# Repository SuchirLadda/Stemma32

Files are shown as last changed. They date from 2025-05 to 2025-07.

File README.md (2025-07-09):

# Stemma32
Custom STM32 dev board with UART, I²C, USB, and SWD interfaces. Designed in KiCad for embedded prototyping.

## Overview
A custom-designed STM32 development board featuring UART, I²C, and USB communication interfaces, intended for embedded systems prototyping and peripheral interfacing. This board is built around the STM32F103C8T6 microcontroller and includes key components such as an external crystal oscillator, onboard boot configuration switch, SWD programming header, and power regulation circuitry.

Pin layout and peripheral configuration were assisted by STM32CubeIDE, which was used to validate the pin mappings and peripheral assignments during design.

## Features
- STM32F103C8T6 MCU
- USB-to-Serial (UART) communication
- UART and I²C breakout for peripherals
- SWD programming/debug interface
- Onboard 3.3V AMS1117 voltage regulator
- External 8 MHz crystal oscillator
- Boot configuration slide switch  
- KiCad 8 project files included

## Repository Contents
- `/kicad/` – Schematic and PCB layout
- `/images/` – 3D model and board render

### Front View – 3D PCB Render
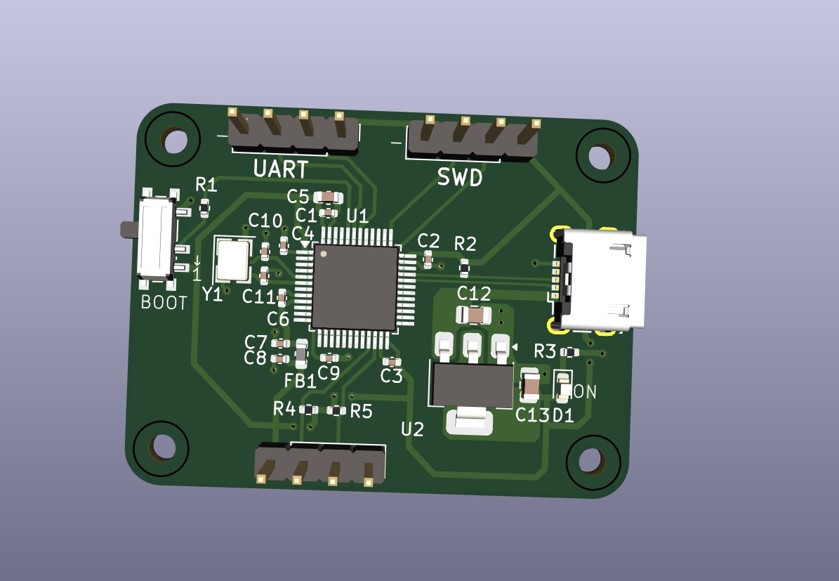
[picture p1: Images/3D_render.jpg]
STM32 Board Render


### Rear View – 3D PCB Render
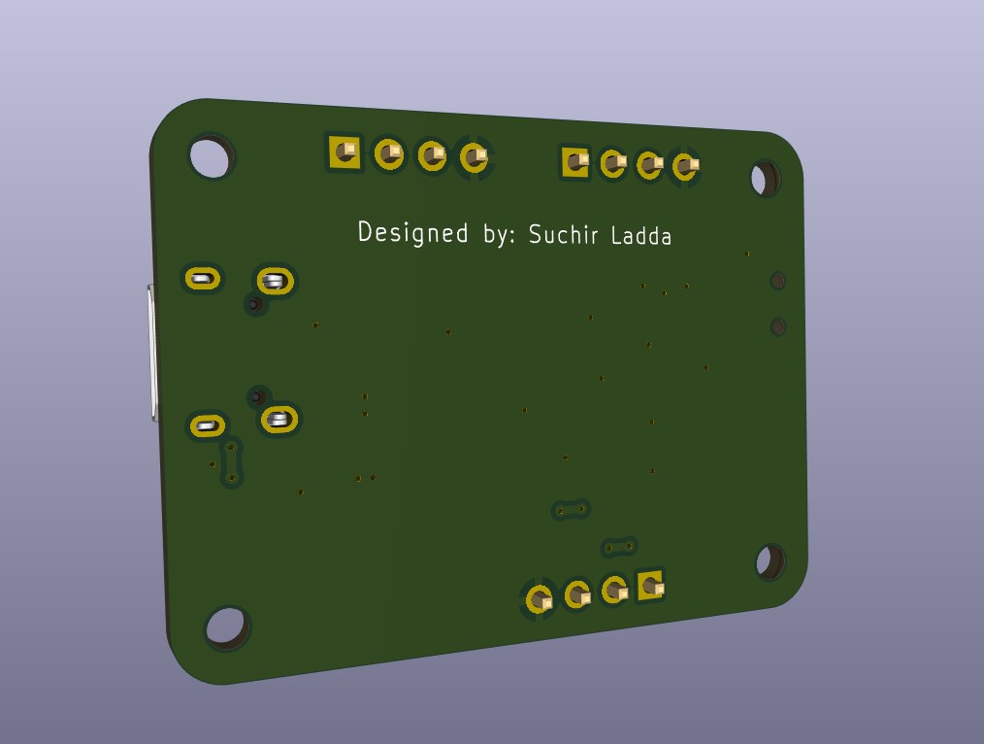
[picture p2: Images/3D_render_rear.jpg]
STM32 Board Render


## 🤝 Sponsorship

This board was manufactured and assembled with the generous support of **[PCBWay](https://www.pcbway.com/)**.

The production quality and turnaround time were excellent. From fabrication to component assembly, everything arrived perfectly aligned and functional.

PCBWay’s engineering team responds quickly and is very understanding when it comes to resolving issues in the assembly process. I highly recommend them for custom PCB projects.

## Physical Board Photos

### Assembled Board – Front
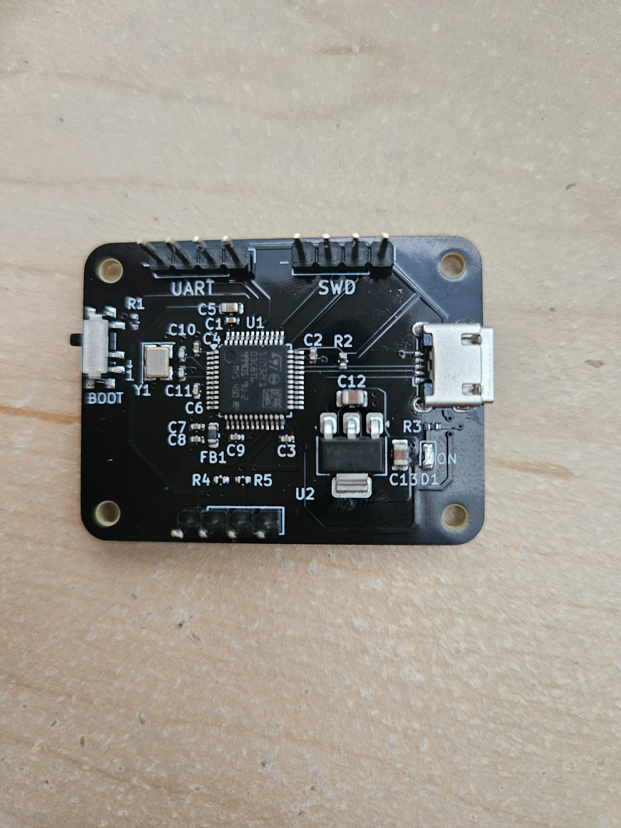
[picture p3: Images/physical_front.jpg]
STM32 Board Front


### Assembled Board – Rear
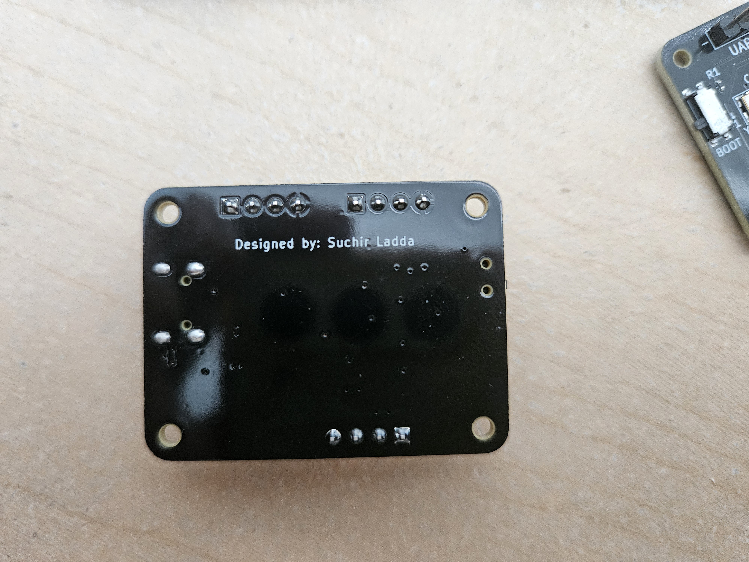
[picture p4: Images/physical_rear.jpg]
STM32 Board Rear


### Power Indicator Test
Power LED On

### All Units Assembled
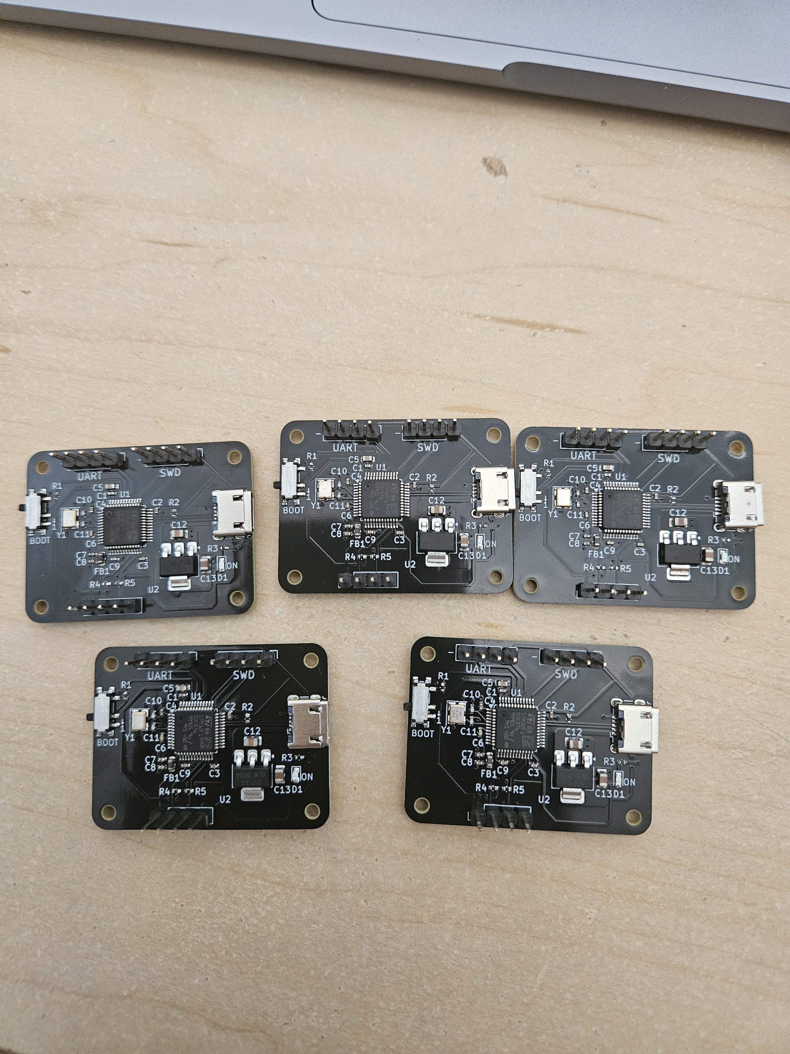
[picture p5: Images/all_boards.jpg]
Batch of Boards


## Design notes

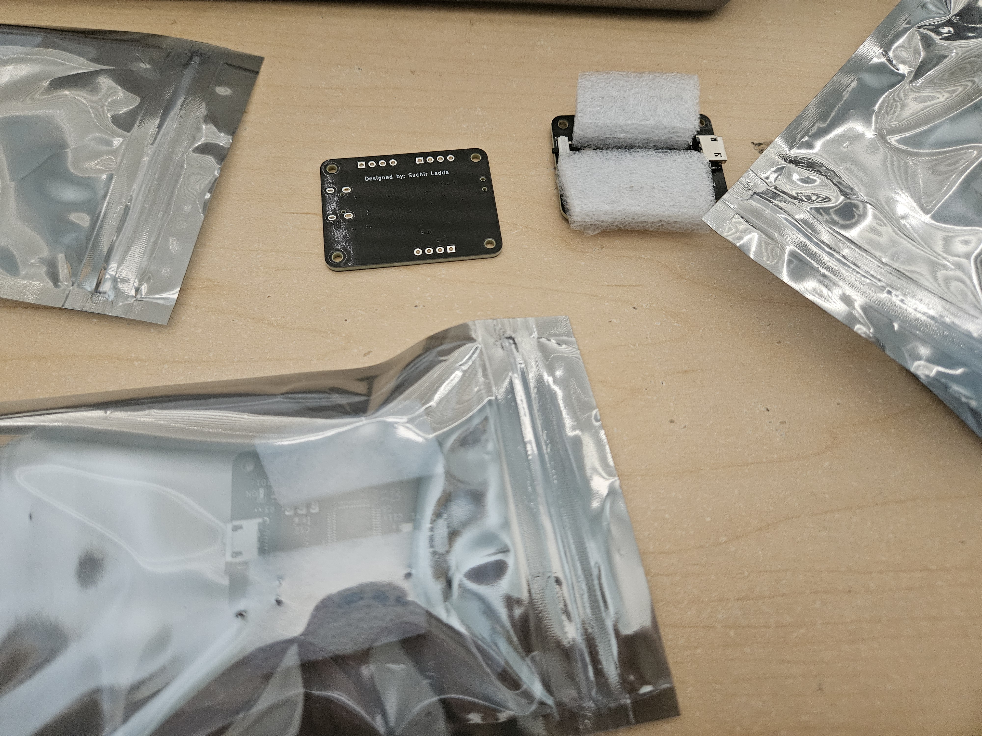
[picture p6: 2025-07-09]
Images/package.jpg

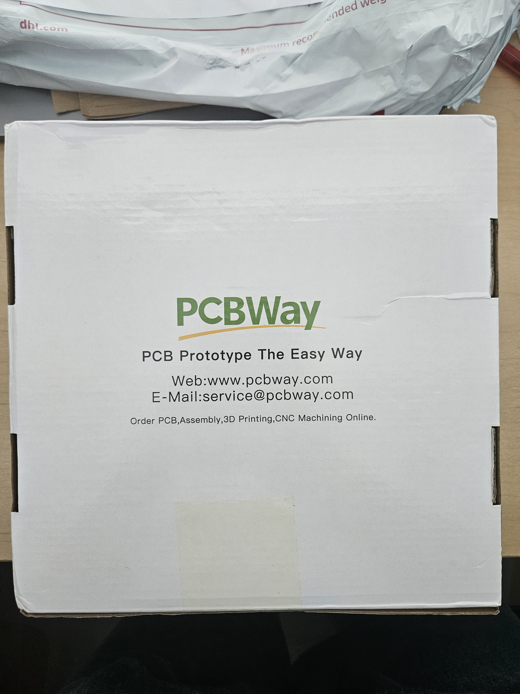
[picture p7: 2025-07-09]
Images/box.jpg

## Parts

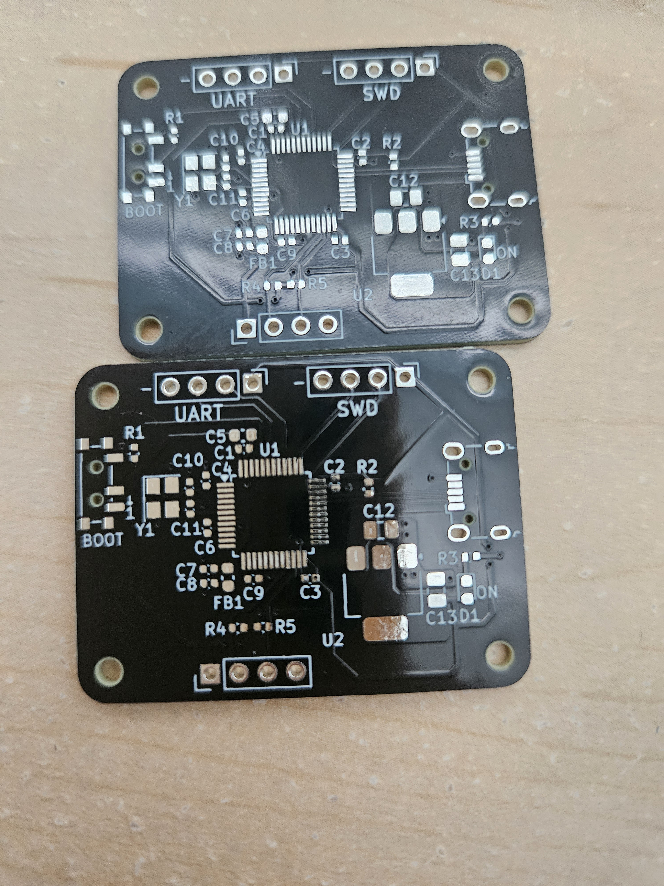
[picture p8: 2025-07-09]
Images/no_components.jpg

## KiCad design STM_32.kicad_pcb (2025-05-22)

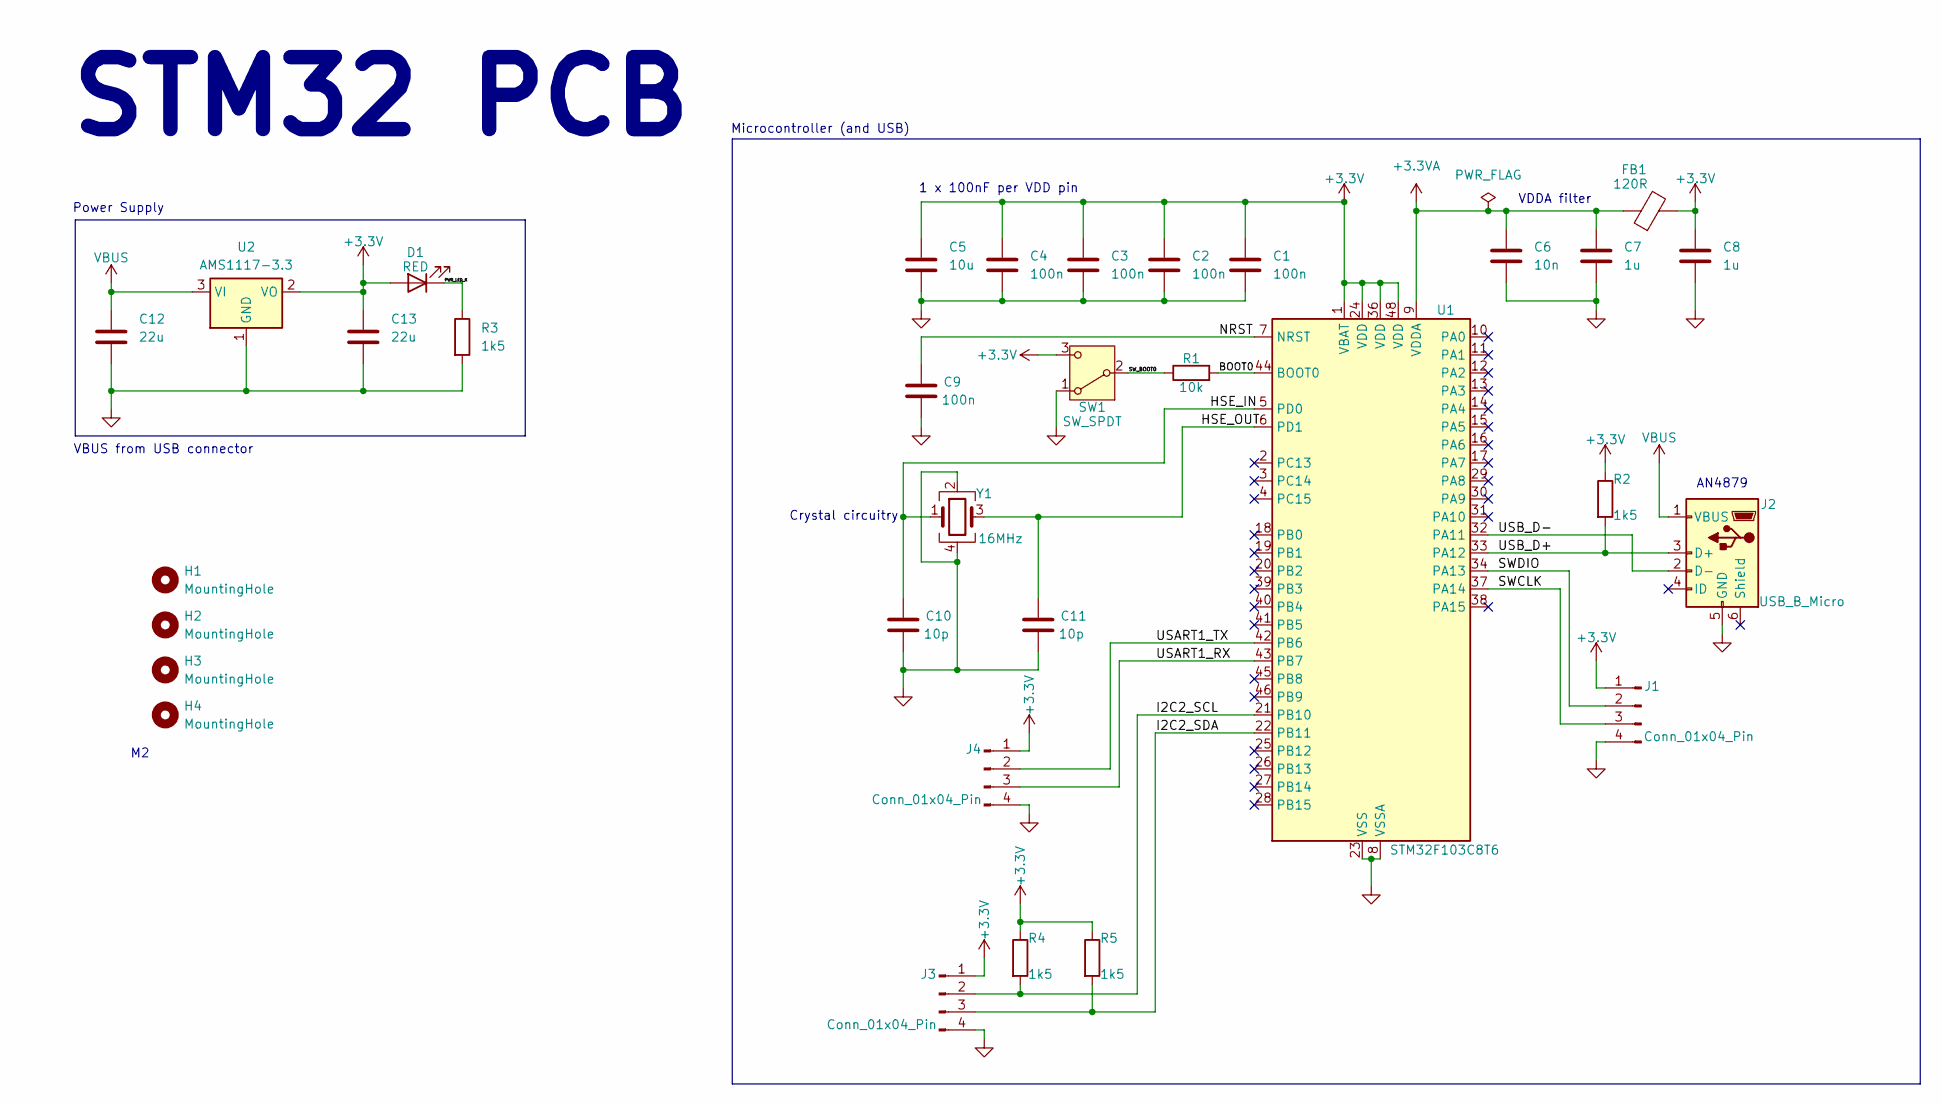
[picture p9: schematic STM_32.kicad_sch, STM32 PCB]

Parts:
C1, C2, C3, C4, C9: 100n; C_0402_1005Metric
C5: 10u; C_0603_1608Metric
C6: 10n; C_0402_1005Metric
C7, C8: 1u; C_0402_1005Metric
C10, C11: 10p; C_0402_1005Metric
C12, C13: 22u; C_0805_2012Metric
D1: RED; LED_0603_1608Metric
FB1: 120R; L_0603_1608Metric
H1, H2, H3, H4: MountingHole; MountingHole_2.2mm_M2
J1, J3, J4: Conn_01x04_Pin; PinHeader_1x04_P2.54mm_Vertical
J2: USB_B_Micro; USB_Micro-B_Wuerth_629105150521
R1: 10k; R_0402_1005Metric
R2, R3, R4, R5: 1k5; R_0402_1005Metric
SW1: SW_SPDT; SW_SPDT_PCM12
U1: STM32F103C8T6; LQFP-48_7x7mm_P0.5mm
U2: AMS1117-3.3; SOT-223-3_TabPin2
Y1: 16MHz; Crystal_SMD_3225-4Pin_3.2x2.5mm

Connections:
+3.3V: C1.1, C2.1, C3.1, C4.1, C5.1, C8.1, C13.1, D1.2 (A), FB1.2, J1.1, J3.1, J4.1, R2.1, R4.1, R5.1, SW1.3 (C), U1.1 (VBAT), U1.24 (VDD), U1.36 (VDD), U1.48 (VDD), U2.2 (VO)
+3.3VA: C6.1, C7.1, FB1.1, U1.9 (VDDA)
/BOOT0: R1.2, U1.44 (BOOT0)
/HSE_IN: C10.1, U1.5 (PD0), Y1.1
/HSE_OUT: C11.1, U1.6 (PD1), Y1.3
/I2C2_SCL: J3.2, R4.2, U1.21 (PB10)
/I2C2_SDA: J3.3, R5.2, U1.22 (PB11)
/NRST: C9.1, U1.7 (NRST)
/PWR_LED_K: D1.1 (K), R3.1
/SWCLK: J1.3, U1.37 (PA14)
/SWDIO: J1.2, U1.34 (PA13)
/SW_BOOT0: R1.1, SW1.2 (B)
/USART1_RX: J4.3, U1.43 (PB7)
/USART1_TX: J4.2, U1.42 (PB6)
/USB_D+: J2.3 (D+), R2.2, U1.33 (PA12)
/USB_D-: J2.2 (D-), U1.32 (PA11)
GND: C1.2, C2.2, C3.2, C4.2, C5.2, C6.2, C7.2, C8.2, C9.2, C10.2, C11.2, C12.2, C13.2, J1.4, J2.5 (GND), J3.4, J4.4, R3.2, SW1.1 (A), U1.8 (VSSA), U1.23 (VSS), U1.35 (VSS), U1.47 (VSS), U2.1 (GND), Y1.2, Y1.4
VBUS: C12.1, J2.1 (VBUS), U2.3 (VI)

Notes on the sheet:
Crystal circuitry
STM32 PCB
AN4879
VDDA filter
Microcontroller (and USB)
1 x 100nF per VDD pin
Power Supply
VBUS from USB connector

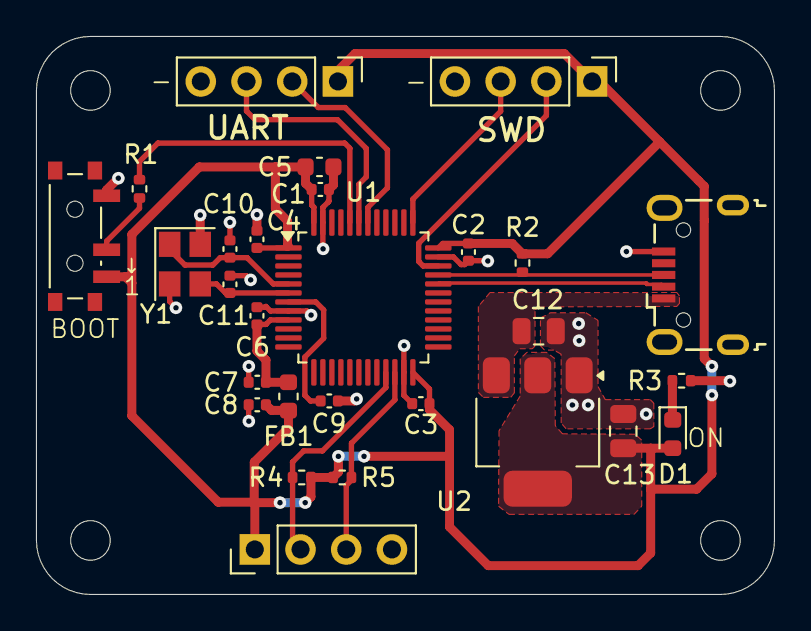
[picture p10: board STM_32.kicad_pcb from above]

Board: 2 copper layers, 41.0 x 31.0 mm, 32 parts (0 on the bottom side), 18 nets.
